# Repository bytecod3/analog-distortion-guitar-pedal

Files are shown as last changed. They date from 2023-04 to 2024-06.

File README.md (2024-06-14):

# analog-distortion-guitar-pedal
Analog distortion guitar pedal 

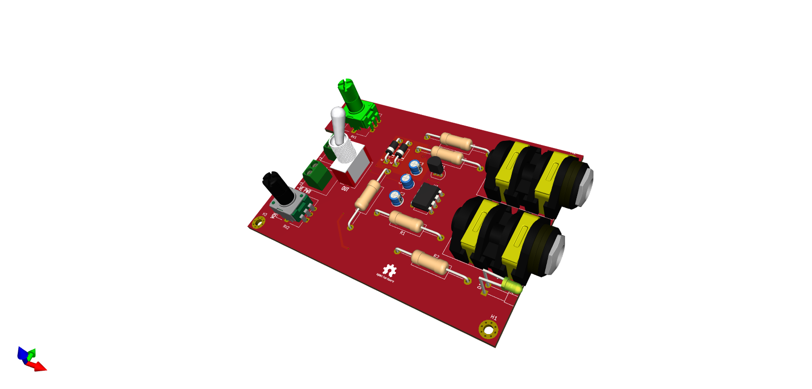
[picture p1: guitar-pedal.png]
PCB


This is a mono analog guitar distortion pedal.

It contains a tunable low pass filter with a BW of 2KHz, gain ranging from 20dB to 40dB, an NPN transistor amplifier stage, an analog clipping circuit for waveform distortion and an output volume control knob.

Input and output is fed by a 6.35mm TRS audio jack.

### Simulations

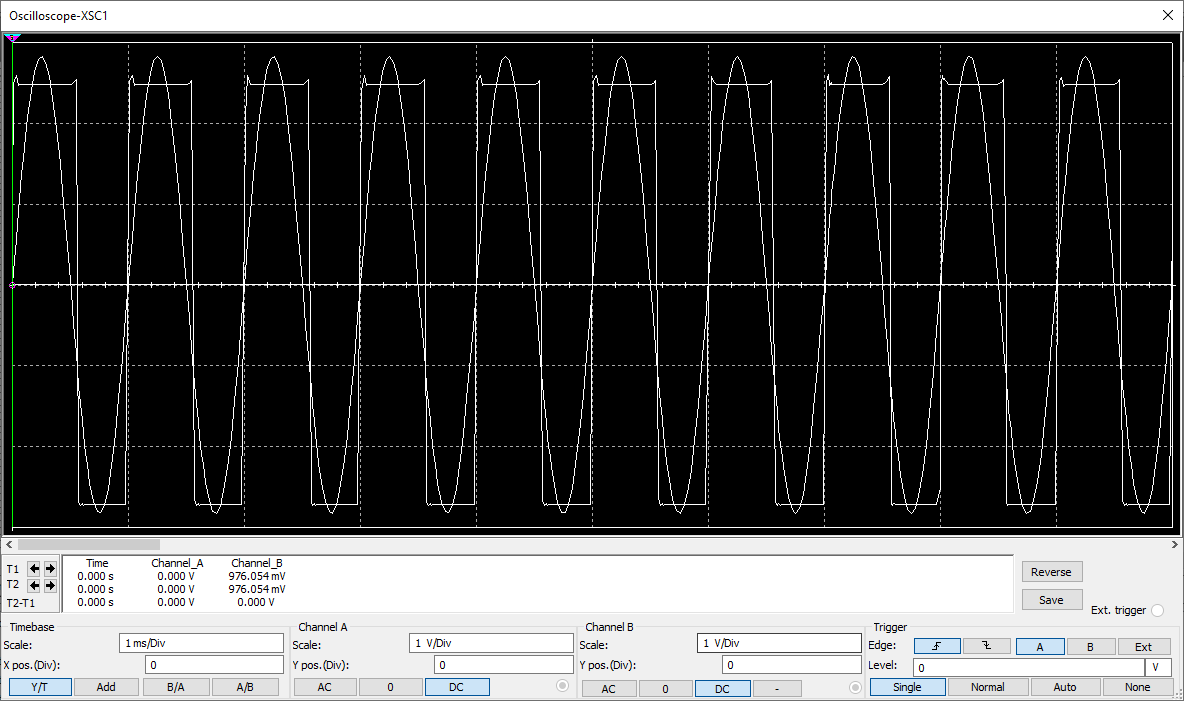
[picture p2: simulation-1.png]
sims


The waveform above shows how the sinusoidal input wave is clipped into a square wave.

### Power supply

Power supply is a 9V DC split.

### 3D casing view 

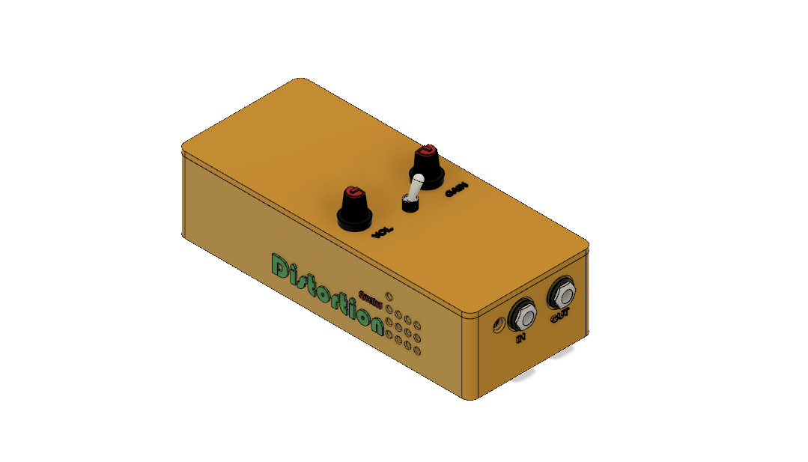
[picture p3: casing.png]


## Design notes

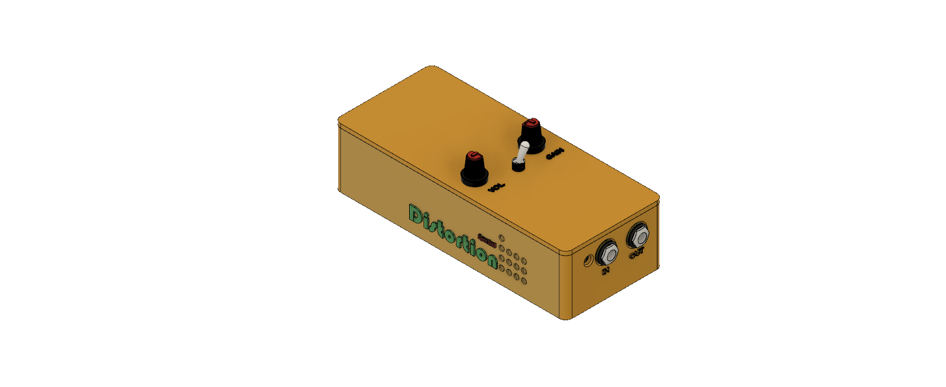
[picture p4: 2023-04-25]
guitar-pedal-ortho-view.png

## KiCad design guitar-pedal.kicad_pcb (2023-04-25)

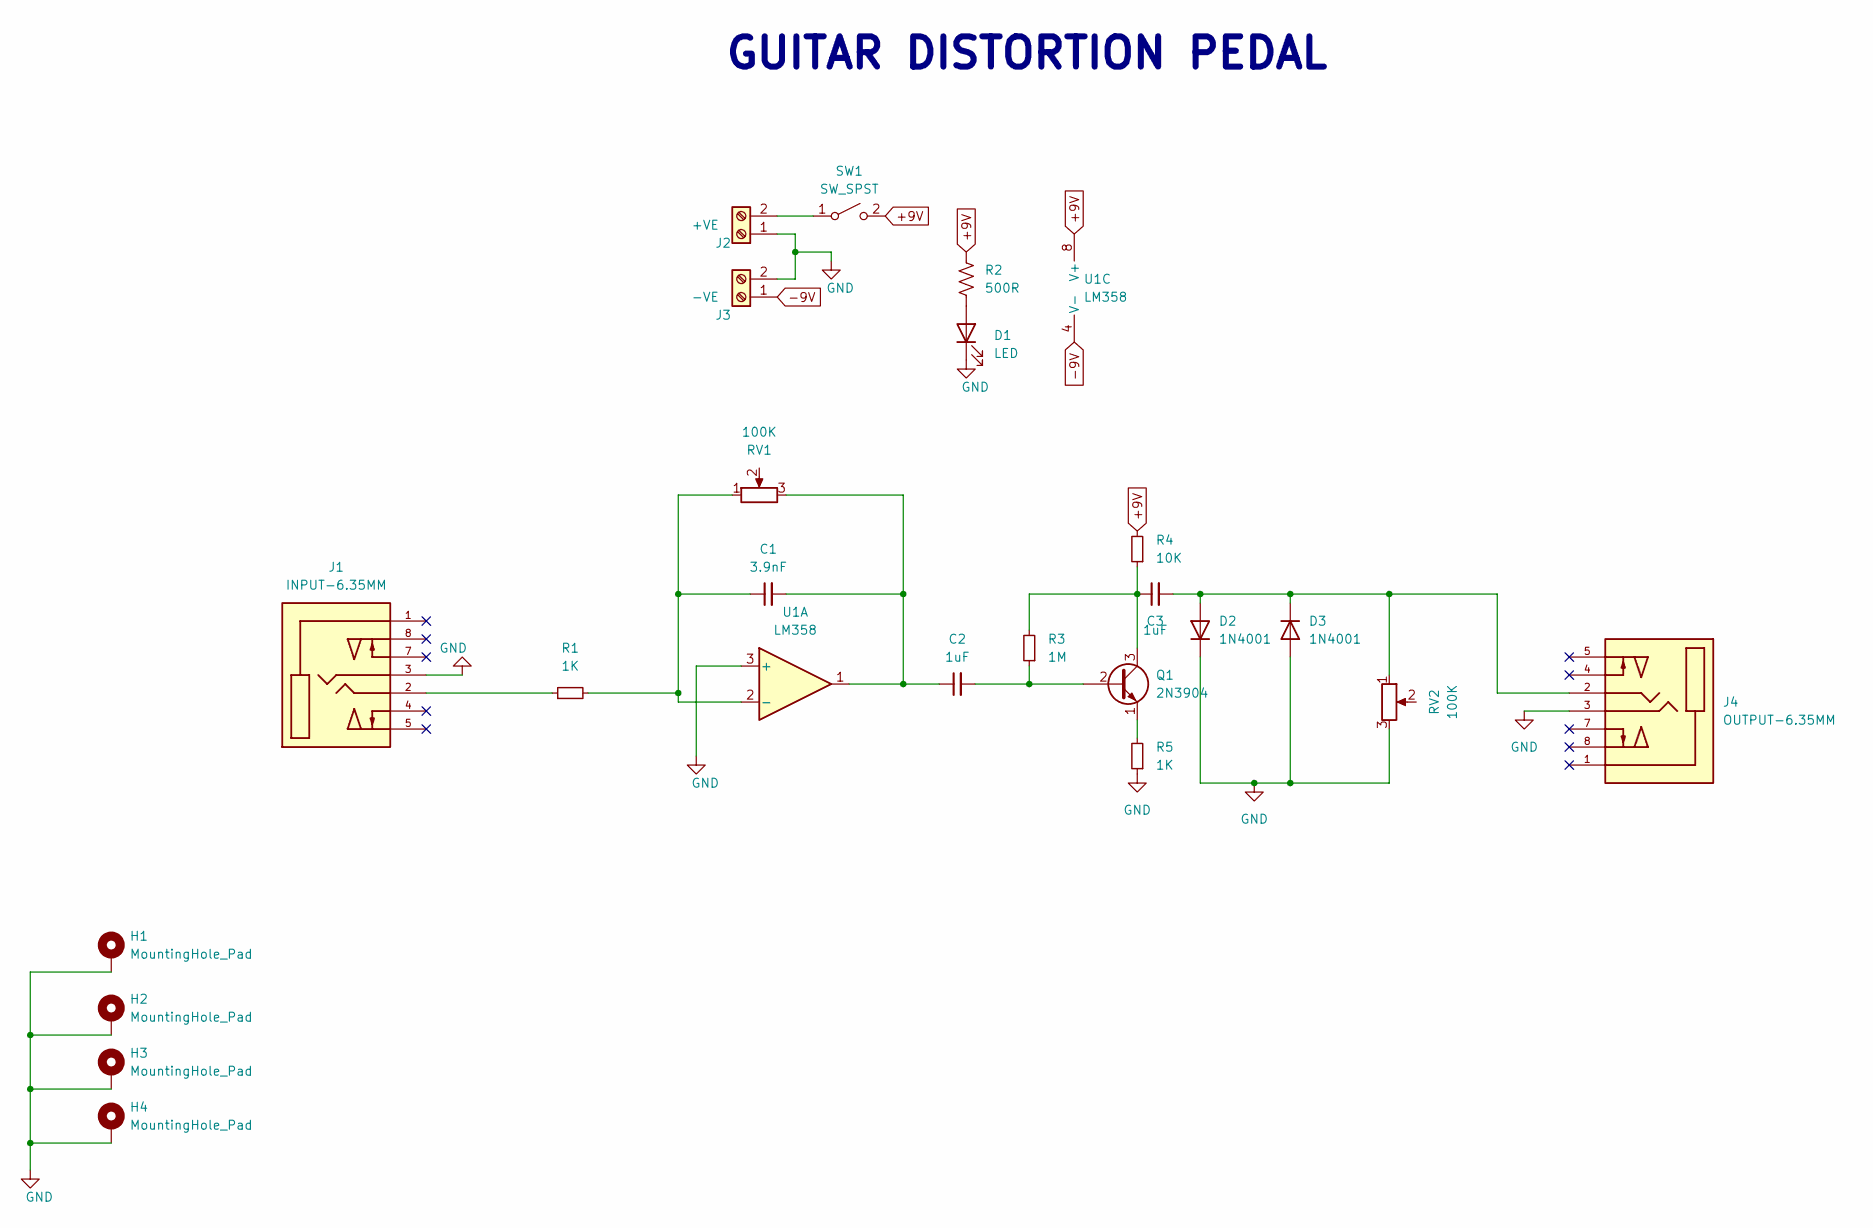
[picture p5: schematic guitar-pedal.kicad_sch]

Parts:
C1: 3.9nF; CP_Radial_D4.0mm_P2.00mm
C2, C3: 1uF; CP_Radial_D4.0mm_P2.00mm
D1: LED; LED_D3.0mm_Horizontal_O6.35mm_Z10.0mm
D2, D3: 1N4001; D_DO-41_SOD81_P10.16mm_Horizontal
H1, H2, H3, H4: MountingHole_Pad; MountingHole_2.7mm_M2.5_Pad_Via
J1: INPUT-6.35MM; CUI_SJ-63043H; PARTREV 1.0
J2: +VE; TerminalBlock_Altech_AK300-2_P5.00mm
J3: -VE; TerminalBlock_Altech_AK300-2_P5.00mm
J4: OUTPUT-6.35MM; CUI_SJ-63043H; PARTREV 1.0
Q1: 2N3904; TO-92_Inline
R1, R5: 1K; R_Axial_DIN0414_L11.9mm_D4.5mm_P25.40mm_Horizontal
R2: 500R; R_Axial_DIN0414_L11.9mm_D4.5mm_P25.40mm_Horizontal
R3: 1M; R_Axial_DIN0414_L11.9mm_D4.5mm_P25.40mm_Horizontal
R4: 10K; R_Axial_DIN0414_L11.9mm_D4.5mm_P25.40mm_Horizontal
RV1, RV2: 100K; Potentiometer_Alps_RK09L_Single_Vertical
SW1: SW_SPST; SW_100SP1T1B4M2QE
U1: LM358; DIP-8_W7.62mm

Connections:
+9V: R2.1, R4.2, SW1.2 (B), U1.8 (V+)
-9V: J3.1, U1.4 (V-)
GND: D1.1 (K), D2.1 (K), D3.2 (A), H1.1, H2.1, H3.1, H4.1, J1.3, J2.1, J3.2, J4.3, R5.1, RV2.3, U1.3 (+)
unnamed: C1.1, R1.2, RV1.1, U1.2 (-)
unnamed: C1.2, C2.1, RV1.3, U1.1
unnamed: C2.2, Q1.2 (B), R3.1
unnamed: C3.1, Q1.3 (C), R3.2, R4.1
unnamed: C3.2, D2.2 (A), D3.1 (K), J4.2, RV2.1
unnamed: D1.2 (A), R2.2
unnamed: J1.2, R1.1
unnamed: J2.2, SW1.1 (A)
unnamed: Q1.1 (E), R5.2

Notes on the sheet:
GUITAR DISTORTION PEDAL

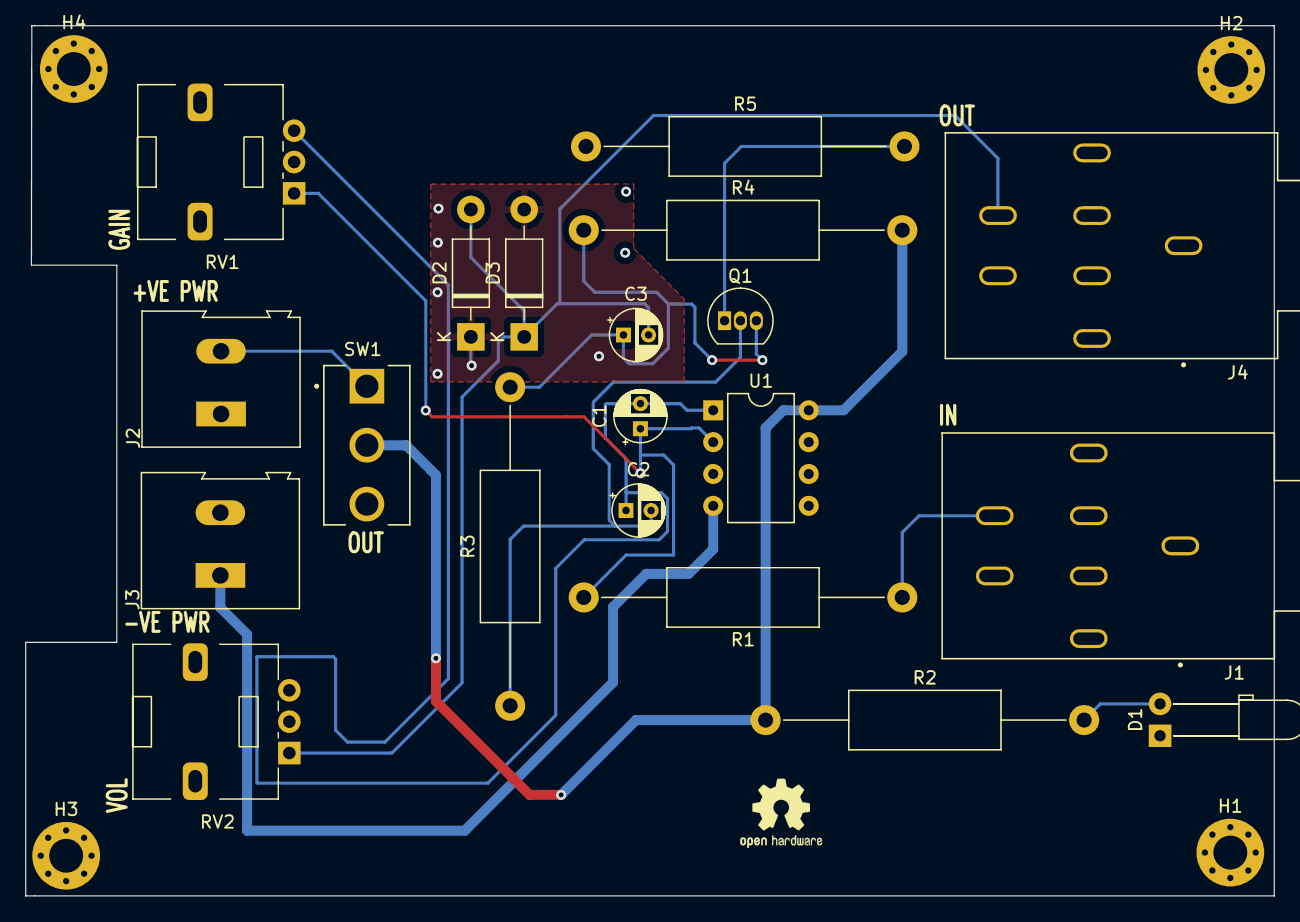
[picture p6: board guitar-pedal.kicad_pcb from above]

Board: 2 copper layers, 99.6 x 69.4 mm, 24 parts (0 on the bottom side), 12 nets.
